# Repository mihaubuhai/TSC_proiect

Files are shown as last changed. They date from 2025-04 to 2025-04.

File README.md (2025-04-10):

# OpenBook e-book reader

## BOM - Bill of Materials

| Component | Datasheet | Vendor |
| --- | ---| ---|
| 112A-TAAR-R03_ATTEND | [datasheet](https://www.attend.com.tw/en/product.php?act=view&id=253) | [vendor](https://www.digikey.com/en/products/detail/attend-technology/112A-TAAR-R03/17633923) |
| BD5229G-TR | [datasheet](https://www.digikey.ph/en/products/detail/rohm-semiconductor/BD5229G-TR/658502) | [vendor](https://www.digikey.ph/en/products/detail/rohm-semiconductor/BD5229G-TR/658502) |
| BUTTON_COSYOMV1 | [datasheet](https://components101.com/switches/push-button) | [vendor](https://uk.farnell.com/wurth-elektronik/430182043816/switch-160gf-6x6mm-smd-4-3mm-act/dp/2065105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) |
| CPH3225A | [datasheet](https://www.digikey.com/en/products/detail/seiko-instruments/CPH3225A/8692444) | [vendor](https://www.digikey.com/en/products/detail/seiko-instruments/CPH3225A/8692444) |
| DS3231SN | [datasheet](https://www.digikey.com/en/products/detail/analog-devices-inc-maxim-integrated/DS3231SN/1197576) | [vendor](https://www.digikey.com/en/products/detail/analog-devices-inc-maxim-integrated/DS3231SN/1197576) |
| BME680 | [datasheet](https://www.sparkfun.com/sparkfun-environmental-sensor-breakout-bme680-qwiic.html) | [vendor](https://www.sparkfun.com/sparkfun-environmental-sensor-breakout-bme680-qwiic.html) |
| MCP73831 | [datasheet](https://www.microchip.com/en-us/product/mcp73831) | [vendor](https://www.microchipdirect.com/product/MCP73831T-2ADI/OT) |
| C6-WROOM-1-N8 | [datasheet](https://www.espressif.com/sites/default/files/documentation/esp32-c6-wroom-1_wroom-1u_datasheet_en.pdf) | [vendor](https://www.adafruit.com/product/5671) |
| FH34SRJ-24S-0.5SH_99_ | [datasheet](https://www.hirose.com/product/p/CL0580-1255-6-99) | [vendor](https://www.hirose.com/product/p/CL0580-1255-6-99) |
| MAX17048G+T10 | [datasheet](https://eu.mouser.com/ProductDetail/Analog-Devices-Maxim-Integrated/MAX17048G+T10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) | [vendor](https://eu.mouser.com/ProductDetail/Analog-Devices-Maxim-Integrated/MAX17048G+T10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) |
| MBR0530 | [datasheet](https://www.digikey.com/en/products/detail/onsemi/MBR0530/1048783) | [vendor](https://www.digikey.com/en/products/detail/onsemi/MBR0530/1048783) |
| PGB1010603MR | [datasheet](https://www.digikey.com/en/products/detail/littelfuse-inc/PGB1010603MR/715755) | [vendor](https://www.digikey.com/en/products/detail/littelfuse-inc/PGB1010603MR/715755) |
| SAMACSYS_PARTS_USB4110-GF-A | [datasheet](https://www.digikey.ro/en/products/detail/gct/USB4110-GF-A/10384547) | [vendor](https://www.digikey.ro/en/products/detail/gct/USB4110-GF-A/10384547) |
| SI1308EDL-T1-GE3 | [datasheet](https://www.digikey.com/en/products/detail/vishay-siliconix/SI1308EDL-T1-GE3/4876435) | [vendor](https://www.digikey.com/en/products/detail/vishay-siliconix/SI1308EDL-T1-GE3/4876435) |
| SJ | [datasheet](https://www.digikey.com/en/products/detail/cui-devices/SJ1-3514N/738685) | [vendor](https://www.digikey.com/en/products/detail/cui-devices/SJ1-3514N/738685) |
| USBLC6-2SC6Y | [datasheet](https://www.digikey.com/en/products/detail/stmicroelectronics/USBLC6-2SC6Y/2819177) | [vendor](https://www.digikey.com/en/products/detail/stmicroelectronics/USBLC6-2SC6Y/2819177) |
| W25Q512JVEIQ | [datasheet](https://www.digikey.com/en/products/detail/winbond-electronics/W25Q512JVEIQ/10244706) | [vendor](https://www.digikey.com/en/products/detail/winbond-electronics/W25Q512JVEIQ/10244706) |
| XC6220A331MR-G | [datasheet](https://www.digikey.com/en/products/detail/torex-semiconductor-ltd/XC6220B331MR-G/2138177) | [vendor](https://www.digikey.com/en/products/detail/torex-semiconductor-ltd/XC6220B331MR-G/2138177) |
| SD0805S020S1R0 | [datasheet](https://www.digikey.com/en/products/detail/kyocera-avx/SD0805S020S1R0/3749517) | [vendor](https://www.digikey.com/en/products/detail/kyocera-avx/SD0805S020S1R0/3749517) |
| LTSPICE_C 100nF | [datasheet](https://www.digikey.com/en/products/detail/nextgen-components/0402B104K500HI/22601924) | [vendor](https://www.digikey.com/en/products/detail/nextgen-components/0402B104K500HI/22601924) |
| LTSPICE_C 10nF | [datasheet](https://www.amazon.com/ALLECIN-Electrolytic-Capacitor-0-2x0-43in-Capacitors/dp/B0CMQC587X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) | [vendor](https://www.amazon.com/ALLECIN-Electrolytic-Capacitor-0-2x0-43in-Capacitors/dp/B0CMQC587X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) |
| LTSPICE_C 4.7uF | [datasheet](https://www.amazon.com/ALLECIN-Electrolytic-Capacitor-0-2x0-43in-Capacitors/dp/B0CMQC587X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) | [vendor](https://www.amazon.com/ALLECIN-Electrolytic-Capacitor-0-2x0-43in-Capacitors/dp/B0CMQC587X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) |
| LTSPICE_C 1uF | [datasheet](https://www.amazon.com/ALLECIN-Electrolytic-Capacitor-0-2x0-43in-Capacitors/dp/B0CMQC587X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) | [vendor](https://www.amazon.com/ALLECIN-Electrolytic-Capacitor-0-2x0-43in-Capacitors/dp/B0CMQC587X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) |
| LTSPICE_C 0.1uF | [datasheet](https://www.digikey.com/en/products/detail/samsung-electro-mechanics/CL10E104KC8VPNC/20498486) | [vendor](https://www.digikey.com/en/products/detail/samsung-electro-mechanics/CL10E104KC8VPNC/20498486) |
| ADAFRUIT_LED | [datasheet](https://www.adafruit.com/product/4684) | [vendor](https://www.adafruit.com/product/4684) |
| ESP32_VARISTOR | [datasheet](https://uk.rs-online.com/web/p/varistors/9012743) | [vendor](https://uk.rs-online.com/web/p/varistors/9012743) |
| CT3528 (RCL_CPOL-EU) 100uF | [datasheet](https://www.datasheetarchive.com/?q=ct3528) | [vendor](https://ro.mouser.com/ProductDetail/Panasonic/EEU-FS1K101L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) |
| DMG2305UX-7 20V/4.2A/52mO/1.4W | [datasheet](https://www.digikey.com/en/products/detail/diodes-incorporated/DMG2305UX-7/4340667) | [vendor](https://www.digikey.com/en/products/detail/diodes-incorporated/DMG2305UX-7/4340667) |
| IND-4828-WE-TPC-WRE | [datasheet](https://www.axel-gl.com/en/asone/d/64-0172-48/) | [vendor](https://www.axel-gl.com/en/asone/d/64-0172-48/) |
| JS-1MM(QWIIC_CONNECTOR) | [datasheet](https://www.sparkfun.com/qwiic-jst-connector-smd-4-pin-horizontal.html) | [vendor](https://www.sparkfun.com/qwiic-jst-connector-smd-4-pin-horizontal.html) |
| LTSPICE_R 5k1 | [datasheet](https://www.vishay.com/docs/53046/pfrr.pdf) | [vendor](https://www.amazon.com/BOJACK-Values-Resistor-Resistors-Assortment/dp/B08FD1XVL6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) |
| LTSPICE_R 100k | [datasheet](https://www.vishay.com/docs/53046/pfrr.pdf) | [vendor](https://www.amazon.com/BOJACK-Values-Resistor-Resistors-Assortment/dp/B08FD1XVL6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) |
| LTSPICE_R 2.2 | [datasheet](https://www.vishay.com/docs/53046/pfrr.pdf) | [vendor](https://www.amazon.com/BOJACK-Values-Resistor-Resistors-Assortment/dp/B08FD1XVL6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) |
| LTSPICE_R 10k | [datasheet](https://www.vishay.com/docs/53046/pfrr.pdf) | [vendor](https://www.amazon.com/BOJACK-Values-Resistor-Resistors-Assortment/dp/B08FD1XVL6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) |
| LTSPICE_R 0.47 | [datashet](https://www.vishay.com/docs/53046/pfrr.pdf) | [vendor](https://www.amazon.com/BOJACK-Values-Resistor-Resistors-Assortment/dp/B08FD1XVL6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) |
| LTSPICE_R 2k | [datasheet](https://www.vishay.com/docs/53046/pfrr.pdf) | [vendor](https://www.amazon.com/BOJACK-Values-Resistor-Resistors-Assortment/dp/B08FD1XVL6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) |
| LTSPICE_R 200 | [datasheet](https://www.vishay.com/docs/53046/pfrr.pdf) | [vendor](https://www.amazon.com/BOJACK-Values-Resistor-Resistors-Assortment/dp/B08FD1XVL6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) |
| LTSPICE_R 15 | [datasheet](https://www.vishay.com/docs/53046/pfrr.pdf) | [vendor](https://www.amazon.com/BOJACK-Values-Resistor-Resistors-Assortment/dp/B08FD1XVL6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) |
| Test Pad TP20R | [datasheet](https://us.misumi-ec.com/vona2/detail/221005496391/?HissuCode=TP20R-24) | [vendor](https://us.misumi-ec.com/vona2/detail/221005496391/?HissuCode=TP20R-24) |

#
```
        Microcontroler: ESP32-C6-WROOM-1-N1 (U2). Acesta este un microcontroler puternic cu conectivitate
    Wi-Fi, Bluetooth, care gestionează procesarea datelor, comunicațiile și controlul general
    al dispozitivului.

    Alimentare:
        Un conector USB-C furnizează intrarea principală de alimentare.
        Un regulator LDO de tensiune (IC4, XC6220A331MR-G) asigură o tensiune stabilă pentru componente.
        Un controler de încărcare pentru baterii Li-Po (MCP73831) gestionează încărcarea bateriei,
            permițând funcționarea autonomă.
        MAX17048G+T10 (U4) monitorizează nivelul de încărcare al bateriei.

        Stocare de date: O memorie Flash NOR externă (U1, W25Q512JVEIQ) oferă stocare non-volatilă
    pentru jurnalizarea datelor, firmware sau alte informații. Este prezent și un slot pentru card SD
    pentru stocare detașabilă.

        Ceas în timp real (RTC): Modulul RTC DS3231SN (U3) menține o măsurare precisă a timpului,
    esențială pentru marcarea temporală a datelor. Un supercondensator (C10) oferă alimentare de
    rezervă pentru RTC.

        Senzori de mediu: Un senzor BME688 măsoară parametrii de mediu (temperatură, umiditate).

        Afișaj: Un ecran E-Paper este utilizat pentru afișarea informațiilor. Interfața cu ecranul
    include un conector (FH34SR-24S-0.5SH_99) și circuitele de susținere.

    Interfață cu utilizatorul:
        Butoanele Boot și Reset permit controlul sistemului și actualizări de firmware.
        Un buton "Change" oferă o intrare din partea utilizatorului.

    Comunicație: ESP32-C6 oferă capabilități de comunicare wireless (Wi-Fi, Bluetooth).

    Alte componente:
        Dispozitive de protecție ESD (USBLC6-2SC6Y, PEMF050.1) protejează circuitul de descărcări
            electrostatice.
        Paduri de test sunt incluse pentru depanare și testare.
        Un conector Qwiic/Stemma QT permite conectarea ușoară a dispozitivelor externe I2C.
```

### Utilizarea pinilor ESP32-C6
```
    Pini de alimentare: Pinii conectați la 3V3 și GND furnizează alimentare și împământare pentru ESP32-C6.

        Comunicație USB: Pinii conectați la conectorul USB-C (prin protecție ESD) sunt utilizați pentru
    comunicația și alimentarea prin USB.

        Interfață card SD: Pinii conectați la slotul pentru card SD (DAT0, DAT1, DAT2, CMD, CLK) sunt
    utilizați pentru interfața cu cardul SD.

        Comunicație SPI: Pinii conectați la memoria Flash externă (W25Q512JVEIQ) (CS, SCK, DO, DI) sunt
    utilizați pentru comunicația SPI.

        Comunicație I2C: Pinii conectați la RTC (DS3231SN) și la conectorul Qwiic (SDA, SCL) sunt utilizați
    pentru comunicația I2C. Senzorul BME688 utilizează și el I2C, prin tag-ul I2C_PW.

    Pini GPIO:
        Pinii conectați la butoanele Boot, Reset și Change sunt utilizați ca pini de intrare/ieșire
            generală (GPIO) pentru a citi starea butoanelor.
        Pinii conectați la interfața ecranului E-Paper sunt GPIO-uri utilizate pentru a controla afișajul.
        Alți pini GPIO pot fi utilizați pentru semnale de control sau indicatori de stare.
```

# ERORI ACCEPTATE
```
        Am acceptat erorile cauzate de nerutarea pinilor GND deoarece am deja 2 planuri de masă puse pe pe placă,
    iar eu consider că nu este necesară rutarea acestor pini între ei, în final ei legându-se la masă.
```

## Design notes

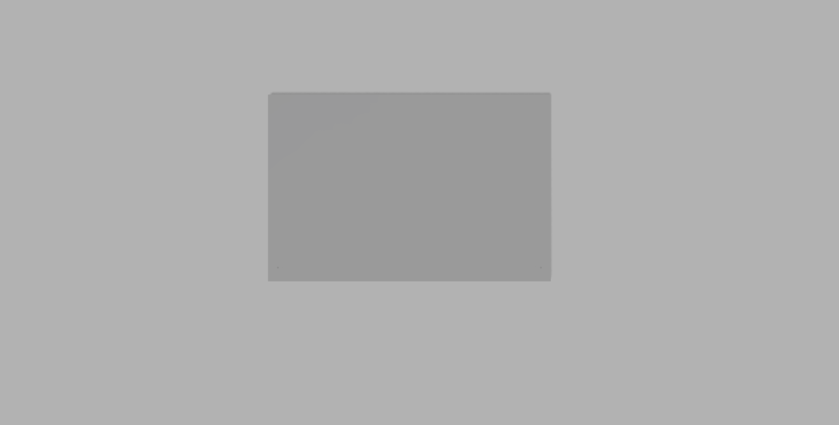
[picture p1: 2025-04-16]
Images/EpaperDisply v1 v1.png

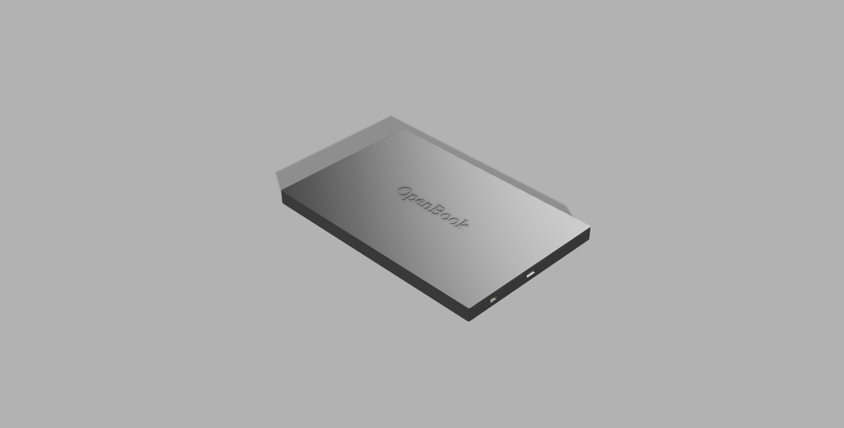
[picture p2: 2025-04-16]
Images/OpenBook Enclosure v4.png

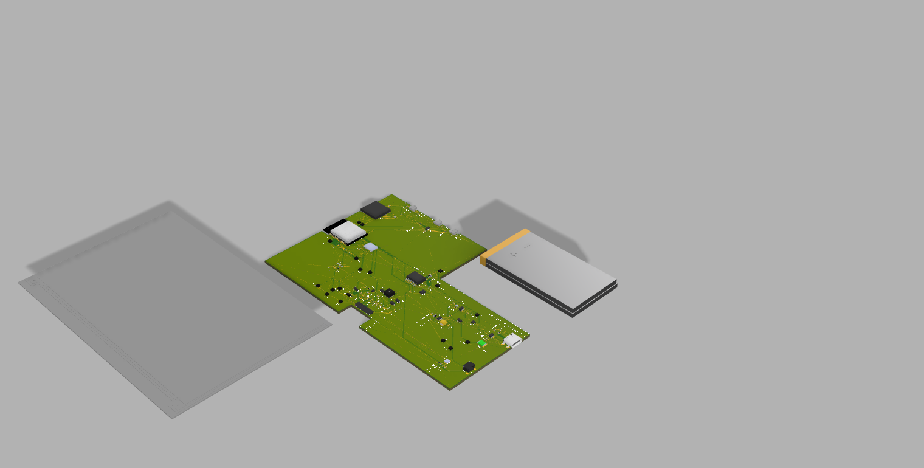
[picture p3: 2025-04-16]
Images/OpenBook Enclosure v5.png

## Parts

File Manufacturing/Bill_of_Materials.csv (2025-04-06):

Qty | Value | Device | Package | Parts | Description | ARROW_PART_NUMBER | ARROW_PRICE-STOCK | AVAILABILITY | CENTROID_NOT_SPECIFIED | CHECK_PRICES | COPYRIGHT | DATASHEET | DESCRIPTION | DIGIKEY_DESCRIPTION | DIGIKEY_PART_NUMBER | HEIGHT | LEAD_FREE | MANUFACTURER_NAME | MANUFACTURER_PART_NUMBER | MF | MFR_NAME | MOUSER_PART_NUMBER | MOUSER_PRICE-STOCK | MOUSER_TESTING_PART_NUMBER | MOUSER_TESTING_PRICE-STOCK | MP | MPN | PACKAGE | POPULARITY | PREFIX | PRICE | PROD_ID | PURCHASE-URL | ROHS | SNAPEDA_LINK | SPICEMODEL | SPICEPREFIX | TEMPERATURE_RANGE_HIGH | TEMPERATURE_RANGE_LOW | TP_SIGNAL_NAME | VALUE
1 |  | ADAFRUIT_LEDCHIP-LED0603 | ADAFRUIT_CHIP-LED0603 | CHG_LED | LED
1 |  | SJ | SJ | SJ1 | SMD solder JUMPER |  |  |  |  |  |  |  |  |  |  |  |  |  |  |  |  |  |  |  |  |  |  |  | 3
1 | 0.1uF/50V | ESP32_WROVER_EAGLE-LTSPICE_CC0402 | ESP32_WROVER_EAGLE-LTSPICE_C0402 | EPD_C5 | CAPACITOR, European symbol |  |  |  |  |  |  |  |  |  |  |  |  |  |  |  |  |  |  |  |  |  |  |  |  |  |  |  |  |  |  | NONE | C
1 | 0.47 | ESP32_WROVER_EAGLE-LTSPICE_RR0402 | ESP32_WROVER_EAGLE-LTSPICE_R0402 | R3 | RESISTOR, European symbol |  |  |  |  |  |  |  |  |  |  |  |  |  |  |  |  |  |  |  |  |  |  |  |  |  |  |  |  |  |  | NONE | R
1 | 100k | ESP32_WROVER_EAGLE-LTSPICE_RR0402 | ESP32_WROVER_EAGLE-LTSPICE_R0402 | R1_PWRUSB | RESISTOR, European symbol |  |  |  |  |  |  |  |  |  |  |  |  |  |  |  |  |  |  |  |  |  |  |  |  |  |  |  |  |  |  | NONE | R
8 | 100nF | ESP32_WROVER_EAGLE-LTSPICE_CC0402 | ESP32_WROVER_EAGLE-LTSPICE_C0402 | C1, C2, C4_USB, C6, C8, C9, C10, C_DELAY | CAPACITOR, European symbol |  |  |  |  |  |  |  |  |  |  |  |  |  |  |  |  |  |  |  |  |  |  |  |  |  |  |  |  |  |  | NONE | C
1 | 100uF TANT | RCL_CPOL-EUCT3528 | RCL_CT3528 | C3 | POLARIZED CAPACITOR, European symbol |  |  |  |  |  |  |  |  |  |  |  |  |  |  |  |  |  |  |  |  |  |  |  | 0 |  |  |  |  |  |  |  | C
16 | 10k | ESP32_WROVER_EAGLE-LTSPICE_RR0402 | ESP32_WROVER_EAGLE-LTSPICE_R0402 | R1, R1_PINH, R1_PINH1, R2_PINH, R2_PINH1, R4, R5, R6, R7, R8, R9, R10, R_BOOT, R_CHANGE, R_CL1, R_RESET | RESISTOR, European symbol |  |  |  |  |  |  |  |  |  |  |  |  |  |  |  |  |  |  |  |  |  |  |  |  |  |  |  |  |  |  | NONE | R
1 | 10uF | ESP32_WROVER_EAGLE-LTSPICE_CC0402 | ESP32_WROVER_EAGLE-LTSPICE_C0402 | C7 | CAPACITOR, European symbol |  |  |  |  |  |  |  |  |  |  |  |  |  |  |  |  |  |  |  |  |  |  |  |  |  |  |  |  |  |  | NONE | C
1 | 112A-TAAR-R03_ATTEND | 112A-TAAR-R03_ATTEND | 112ATAARR03ATTEND | J4 | Micro SD Card Socket, Push-Push Type, Top Mount, SMT, H=1.83mm, 10u |  |  |  |  |  |  |  | Micro SD Card Socket | Push-Push Type | Top Mount | SMT | H=1.83mm | 10u |  |  | 1.9mm |  | ATTEND | 112A-TAAR-R03 ATTEND
1 | 15 | ESP32_WROVER_EAGLE-LTSPICE_RR0402 | ESP32_WROVER_EAGLE-LTSPICE_R0402 | R_CAPACITOR | RESISTOR, European symbol |  |  |  |  |  |  |  |  |  |  |  |  |  |  |  |  |  |  |  |  |  |  |  |  |  |  |  |  |  |  | NONE | R
1 | 1uF | ESP32_WROVER_EAGLE-LTSPICE_CC0402 | ESP32_WROVER_EAGLE-LTSPICE_C0402 | C5 | CAPACITOR, European symbol |  |  |  |  |  |  |  |  |  |  |  |  |  |  |  |  |  |  |  |  |  |  |  |  |  |  |  |  |  |  | NONE | C
9 | 1uF/50V | ESP32_WROVER_EAGLE-LTSPICE_CC0402 | ESP32_WROVER_EAGLE-LTSPICE_C0402 | EPD_C1, EPD_C2, EPD_C6, EPD_C7, EPD_C8, EPD_C9, EPD_C10, EPD_C11, EPD_C12 | CAPACITOR, European symbol |  |  |  |  |  |  |  |  |  |  |  |  |  |  |  |  |  |  |  |  |  |  |  |  |  |  |  |  |  |  | NONE | C
1 | 2.2 | ESP32_WROVER_EAGLE-LTSPICE_RR0402 | ESP32_WROVER_EAGLE-LTSPICE_R0402 | R2 | RESISTOR, European symbol |  |  |  |  |  |  |  |  |  |  |  |  |  |  |  |  |  |  |  |  |  |  |  |  |  |  |  |  |  |  | NONE | R
1 | 200 | ESP32_WROVER_EAGLE-LTSPICE_RR0402 | ESP32_WROVER_EAGLE-LTSPICE_R0402 | R1_BAT | RESISTOR, European symbol |  |  |  |  |  |  |  |  |  |  |  |  |  |  |  |  |  |  |  |  |  |  |  |  |  |  |  |  |  |  | NONE | R
2 | 20V/4.2A/52mO/1.4W | ESP32_WROVER_SPARKFUN-DISCRETESEMI_MOSFET_PCH-DMG2305UX-7 | ESP32_WROVER_SPARKFUN-DISCRETESEMI_SOT23-3 | Q1, Q2 | P-channel MOSFETs |  |  |  |  |  |  |  |  |  |  |  |  |  |  |  |  |  |  |  |  |  |  |  |  |  |  | TRAN-14388 |  |  |  |  |  |  |  |  | 20V/4.2A/52mO/1.4W
1 | 2k | ESP32_WROVER_EAGLE-LTSPICE_RR0402 | ESP32_WROVER_EAGLE-LTSPICE_R0402 | R2_BAT | RESISTOR, European symbol |  |  |  |  |  |  |  |  |  |  |  |  |  |  |  |  |  |  |  |  |  |  |  |  |  |  |  |  |  |  | NONE | R
5 | 4.7uF | ESP32_WROVER_EAGLE-LTSPICE_CC0402 | ESP32_WROVER_EAGLE-LTSPICE_C0402 | C1_BAT, C1_BAT1, C1_BAT2, C2_BAT, C5_USB | CAPACITOR, European symbol |  |  |  |  |  |  |  |  |  |  |  |  |  |  |  |  |  |  |  |  |  |  |  |  |  |  |  |  |  |  | NONE | C
1 | 4.7uF/25V | ESP32_WROVER_EAGLE-LTSPICE_CC0402 | ESP32_WROVER_EAGLE-LTSPICE_C0402 | C4 | CAPACITOR, European symbol |  |  |  |  |  |  |  |  |  |  |  |  |  |  |  |  |  |  |  |  |  |  |  |  |  |  |  |  |  |  | NONE | C
2 | 5k1 | ESP32_WROVER_EAGLE-LTSPICE_RR0402 | ESP32_WROVER_EAGLE-LTSPICE_R0402 | R2-USB, R2-USB1 | RESISTOR, European symbol |  |  |  |  |  |  |  |  |  |  |  |  |  |  |  |  |  |  |  |  |  |  |  |  |  |  |  |  |  |  | NONE | R
1 | 68uH | 744043680IND_4828-WE-TPC_WRE | IND_4828-WE-TPC_WRE | L1 |  |  |  |  |  |  | Copyright (C) 2024 Ultra Librarian. All rights reserved. |  |  |  |  |  |  |  | 744043680 |  | Wurth Electronics
1 | BD5229G-TR | BD5229G-TR | SOT95P280X125-5N | IC1 | Voltage Detector with Adjustable Delay Time: CMOS processes are utilized to develop high precision, low current consumption CMOS reset ICs that allow arbitrary setting of the delay time. The extensive lineup includes both Nch Open Drain and CMOS output types in a wide range of detection voltages (from 2.3V to 6.0V, in 0.1V steps), enabling selection of the ideal solution based on customer requirements. In addition, the entire series is of course both lead-free and RoHS-compliant. |  |  |  |  |  |  |  | Voltage Detector with Adjustable Delay Time: CMOS processes are utilized to develop high precision | low current consumption CMOS reset ICs that allow arbitrary setting of the delay time. The extensive lineup includes both Nch Open Drain and CMOS output types in a wide range of detection voltages (from 2.3V to 6.0V | in 0.1V steps) | enabling selection of the ideal solution based on customer requirements. In addition | the entire series is of course both lead-free and RoHS-compliant. |  |  | 1.25mm |  | ROHM Semiconductor | BD5229G-TR |  |  | 755-BD5229G-TR | https://www.mouser.co.uk/ProductDetail/ROHM-Semiconductor/BD5229G-TR?qs=4kLU8WoGk0vvnhrrYwdszw%3D%3D
1 | BME688 | ESP32_WROVER_BME680_BME680 | ESP32_WROVER_BME680_PSON80P300X300X100-8N | SENSOR2 | Integrated Environmental Unit |  |  | Unavailable |  |  |  |  | Integrated Environmental Unit |  |  |  |  |  |  | Bosch Sensortec |  |  |  |  |  | BME680 |  | LGA-8 Bosch Tools |  |  | None
3 | BUTTON_CUSYOMV1 | BUTTON_CUSYOMV1 | MYBUTTON | BOOT_BUTTON, CHANGE_BUTTON, RESET_BUTTON
1 | CPH3225A | CPH3225A | CAPCP3225X100N | C10_SUPERCAP | Cap 0.011F 3.3V 1210 Flat Check availability |  |  | Not in stock |  | https://www.snapeda.com/parts/CPH3225A/Seiko+Instruments/view-part/?ref=eda |  |  | 11 mF (EDLC) Supercapacitor 3.3 V 1210 (3225 Metric) - - |  |  |  |  |  |  | Seiko Instruments |  |  |  |  |  | CPH3225A |  | 1210 Seiko |  |  | None |  | https://www.snapeda.com/api/url_track_click_mouser/?unipart_id=562593&manufacturer=Seiko Instruments&part_name=CPH3225A&search_term=None |  | https://www.snapeda.com/parts/CPH3225A/Seiko+Instruments/view-part/?ref=snap
1 | DS3231SN# | DS3231SN# | SOIC127P1032X265-16N | U1 | Real Time Clock Serial 16-Pin SOIC W T/R Check availability |  |  | In Stock |  | https://www.snapeda.com/parts/DS3231SN%23/Analog+Devices/view-part/?ref=eda |  |  | Extremely Accurate I²C-Integrated RTC/TCXO/Crystal |  |  |  |  |  |  | Analog Devices |  |  |  |  |  | DS3231SN# |  | SOIC-16 Maxim |  |  | None |  | https://www.snapeda.com/api/url_track_click_mouser/?unipart_id=99048&manufacturer=Analog Devices&part_name=DS3231SN#&search_term=None |  | https://www.snapeda.com/parts/DS3231SN%23/Analog+Devices/view-part/?ref=snap
1 | ESP32-C6-WROOM-1-N8 | ESP32-C6-WROOM-1-N8 | XCVR_ESP32-C6-WROOM-1-N8 | U2 | Check availability |  |  | In Stock |  | https://www.snapeda.com/parts/ESP32-C6-WROOM-1-N8/Espressif+Systems/view-part/?ref=eda |  |  | Multiprotocol Modules ESP32-C6 module | Wi-Fi 6 in 2.4 GHz band | Bluetooth 5 | Zigbee 3.0 and Thread. ESP34-WROOM Compatible - ENGINEERING SAMPLE |  |  |  |  |  |  | Espressif Systems |  |  |  |  |  | ESP32-C6-WROOM-1-N8 |  | None |  |  | None |  |  |  | https://www.snapeda.com/parts/ESP32-C6-WROOM-1-N8/Espressif+Systems/view-part/?ref=snap
1 | ESP32C6_VARISTORCN1812 | ESP32C6_VARISTORCN1812 | ESP32C6_VARISTOR_CT/CN1812 | PFMF.050.1 | VARISTOR |  |  |  |  |  |  |  |  |  |  |  |  |  |  |  |  |  |  |  |  |  |  |  | 0
2 | ESP32_WROVER_AVX---SD0805S020S1R0_AVX_SD0805S020S1R0_0_0AVX_SD0805S020S1R0_0_0 | ESP32_WROVER_AVX---SD0805S020S1R0_AVX_SD0805S020S1R0_0_0AVX_SD0805S020S1R0_0_0 | ESP32_WROVER_AVX---SD0805S020S1R0_AVX_SD0805S020S1R0_0 | D2, D7 | Schottky Barrier Rectifier Diode |  |  |  | No |  |  | http://datasheets.avx.com/schottky.pdf |  | DIODE SCHOTTKY 20V 1A 0805 | 478-7800-1-ND |  | yes |  |  | AVX |  | 581-SD0805S020S1R0 |  |  |  |  |  | 0805 (2012 metric) |  | D |  |  |  | yes |  |  |  | +125°C | -55°C
1 | ESP32_WROVER_SPARKFUN-IC-POWER_MCP73831 | ESP32_WROVER_SPARKFUN-IC-POWER_MCP73831 | ESP32_WROVER_SPARKFUN-IC-POWER_SOT23-5 | MCP73831 | MCP73831T Li-Ion, Li-Pol Controller |  |  |  |  |  |  |  |  |  |  |  |  |  |  |  |  |  |  |  |  |  |  |  |  |  |  | IC-09995
1 | FH34SRJ-24S-0.5SH_99_ | FH34SRJ-24S-0.5SH_99_ | FH34SRJ24S05SH99 | J1 | (0.50mm) Surface Mount, Right Angle |  |  |  |  |  |  |  | 24 Position FFC | FPC Connector Contacts | (0.50mm) Surface Mount | Right Angle |  |  | 1.1mm |  | Hirose | FH34SRJ-24S-0.5SH(99) |  |  | 798-FH34SRJ24S05SH99 | https://www.mouser.co.uk/ProductDetail/Hirose-Connector/FH34SRJ-24S-0.5SH99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
1 | MAX17048G+T10 | MAX17048G+T10 | SON50P200X200X80-9N | U4 | Check availability |  |  | In Stock |  | https://www.snapeda.com/parts/MAX17048G+T10/Analog+Devices/view-part/?ref=eda |  |  | 3µA 1-Cell/2-Cell Fuel Gauge with ModelGauge |  |  |  |  |  |  | Analog Devices |  |  |  |  |  | MAX17048G+T10 |  | TDFN-8 Maxim |  |  | None |  | https://www.snapeda.com/api/url_track_click_mouser/?unipart_id=329239&manufacturer=Analog Devices&part_name=MAX17048G+T10&search_term=None |  | https://www.snapeda.com/parts/MAX17048G+T10/Analog+Devices/view-part/?ref=snap
3 | MBR0530 | MBR0530 | SOD3716X135N | D3, D4, D5 | ON SEMICONDUCTOR - MBR0530 - DIODE, SCHOTTKY, 0.5A, 30V, SOD-123 |  |  | In Stock |  | https://www.snapeda.com/parts/MBR0530/Onsemi/view-part/?ref=eda |  |  | Diode Schottky 30 V 500mA Surface Mount SOD-123 |  |  |  |  |  |  | ON Semiconductor |  |  |  |  |  | MBR0530 |  | SOD-123-2 ON Semiconductor |  |  | None |  | https://www.snapeda.com/api/url_track_click_mouser/?unipart_id=179458&manufacturer=ON Semiconductor&part_name=MBR0530&search_term=None |  | https://www.snapeda.com/parts/MBR0530/Onsemi/view-part/?ref=snap
6 | PGB1010603MR | PGB1010603MR | DIOC1608X36N | D6, D8, D9, D10, D11, D12 | Check availability |  |  | In Stock |  | https://www.snapeda.com/parts/PGB1010603MR/Littelfuse/view-part/?ref=eda |  |  | 150V (Typ) Clamp - Ipp Tvs Diode Surface Mount 0603 (1608 Metric) |  |  |  |  |  |  | Littelfuse Inc. |  |  |  |  |  | PGB1010603MR |  | 0603 Littelfuse Inc. |  |  | None |  | https://www.snapeda.com/api/url_track_click_mouser/?unipart_id=5659453&manufacturer=Littelfuse Inc.&part_name=PGB1010603MR&search_term=None |  | https://www.snapeda.com/parts/PGB1010603MR/Littelfuse/view-part/?ref=snap
1 | QWIIC_RIGHT_ANGLE | QWIIC_CONNECTORJS-1MM | JST04_1MM_RA | J3 | SparkFun I2C Standard Qwiic Connector |  |  |  |  |  |  |  |  |  |  |  |  |  |  |  |  |  |  |  |  |  |  |  |  |  |  | CONN-13694 |  |  |  |  |  |  |  |  | QWIIC_RIGHT_ANGLE
1 | SAMACSYS_PARTS_USB4110-GF-A | SAMACSYS_PARTS_USB4110-GF-A | SAMACSYS_PARTS_USB4110GFA | J2 | CONN USB 2.0 TYPE-C R/A SMT |  |  |  |  |  |  |  | CONN USB 2.0 TYPE-C R/A SMT |  |  | 3.26mm |  | GCT (GLOBAL CONNECTOR TECHNOLOGY) | USB4110-GF-A |  |  | 640-USB4110-GF-A | https://www.mouser.co.uk/ProductDetail/GCT/USB4110-GF-A?qs=KUoIvG%2F9IlYiZvIXQjyJeA%3D%3D
1 | SI1308EDL-T1-GE3 | SI1308EDL-T1-GE3 | SOT65P210X110-3N | Q3 | MOSFET N-Ch 30V 1.5A TrenchFET SC70 Vishay Si1308EDL-T1-GE3 N-channel MOSFET Transistor, 1.5 A, 30 V, 3-Pin SC-70 |  |  | In Stock |  | https://www.snapeda.com/parts/SI1308EDL-T1-GE3/Vishay+Siliconix/view-part/?ref=eda |  |  | Si1308EDL-T1-GE3 N-channel MOSFET Transistor | 1.5 A | 30 V | 3-Pin SC-70 | Siliconix / Vishay SI1308EDL-T1-GE3 |  |  |  |  |  |  | Vishay Siliconix |  |  |  |  |  | SI1308EDL-T1-GE3 |  | SOT-323 Vishay Semiconductor |  |  | None |  | https://www.snapeda.com/api/url_track_click_mouser/?unipart_id=274603&manufacturer=Vishay Siliconix&part_name=SI1308EDL-T1-GE3&search_term=None |  | https://www.snapeda.com/parts/SI1308EDL-T1-GE3/Vishay+Siliconix/view-part/?ref=snap
17 | TPTP20R | TPTP20R | TP20R | TP1, TP2, TP3, TP4, TP5, TP6, TP7, TP8, TP9, TP10, TP11, TP12, TP13, TP14, TP15, TP16, TP17 | Test pad |  |  |  |  |  |  |  |  |  |  |  |  |  |  |  |  |  |  |  |  |  |  |  | 2
1 | USBLC6-2SC6Y | USBLC6-2SC6Y | SOT95P280X145-6N | D1 | Low Cap. ESD Protection Auto SOT-23-6 STMicroelectronics USBLC6-2SC6Y, Dual Uni-Directional TVS Diode Array, 6-Pin SOT-23 |  |  | In Stock |  | https://www.snapeda.com/parts/USBLC6-2SC6Y/STMicroelectronics/view-part/?ref=eda |  |  | 17V Clamp 5A (8/20µs) Ipp Tvs Diode Surface Mount SOT-23-6 |  |  |  |  |  |  | STMicroelectronics |  |  |  |  |  | USBLC6-2SC6Y |  | SOT-23-6 STMicroelectronics |  |  | None |  |  |  | https://www.snapeda.com/parts/USBLC6-2SC6Y/STMicroelectronics/view-part/?ref=snap
1 | W25Q512JVEIQ | W25Q512JVEIQ | SON127P600X800X80-9N | U3 | Check availability |  |  | In Stock |  | https://www.snapeda.com/parts/W25Q512JVEIQ/Winbond+Electronics/view-part/?ref=eda |  |  | FLASH - NOR Memory IC 512Mb (64M x 8) SPI - Quad I/O 133 MHz 8-WSON (8x6) |  |  |  |  |  |  | Winbond Electronics |  |  |  |  |  | W25Q512JVEIQ |  | Package |  |  | None |  |  |  | https://www.snapeda.com/parts/W25Q512JVEIQ/Winbond+Electronics/view-part/?ref=snap
1 | XC6220A331MR-G | XC6220A331MR-G | SOT95P280X120-5N | IC4 | LDO Voltage Regulators |  |  |  |  |  |  |  | LDO Voltage Regulators |  |  | 1.2mm |  | Torex | XC6220A331MR-G |  |  | 865-XC6220A331MR-G | https://www.mouser.co.uk/ProductDetail/Torex-Semiconductor/XC6220A331MR-G?qs=AsjdqWjXhJ8ZSWznL1J0gg%3D%3D

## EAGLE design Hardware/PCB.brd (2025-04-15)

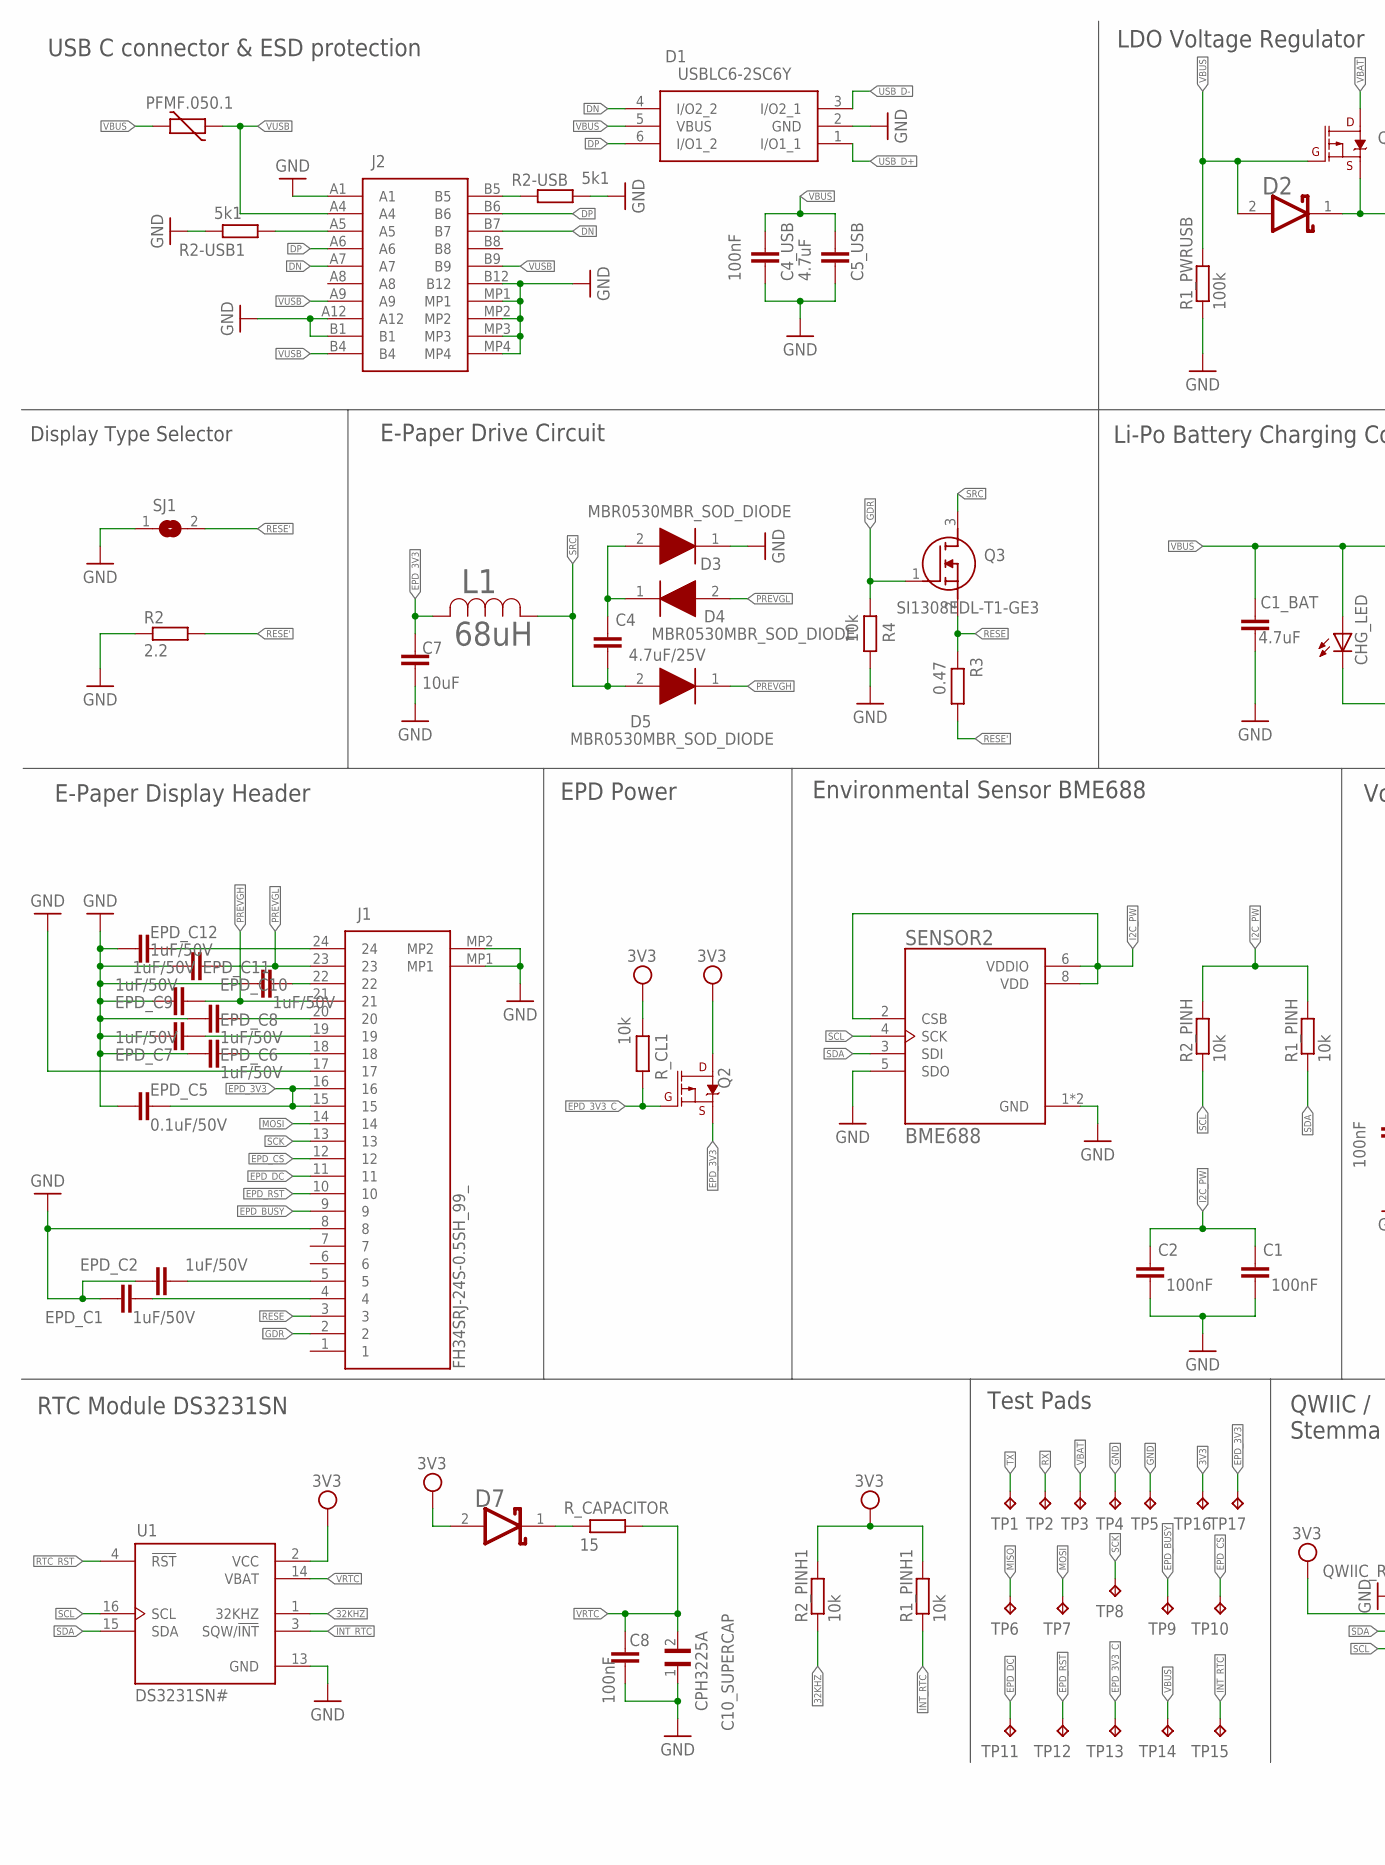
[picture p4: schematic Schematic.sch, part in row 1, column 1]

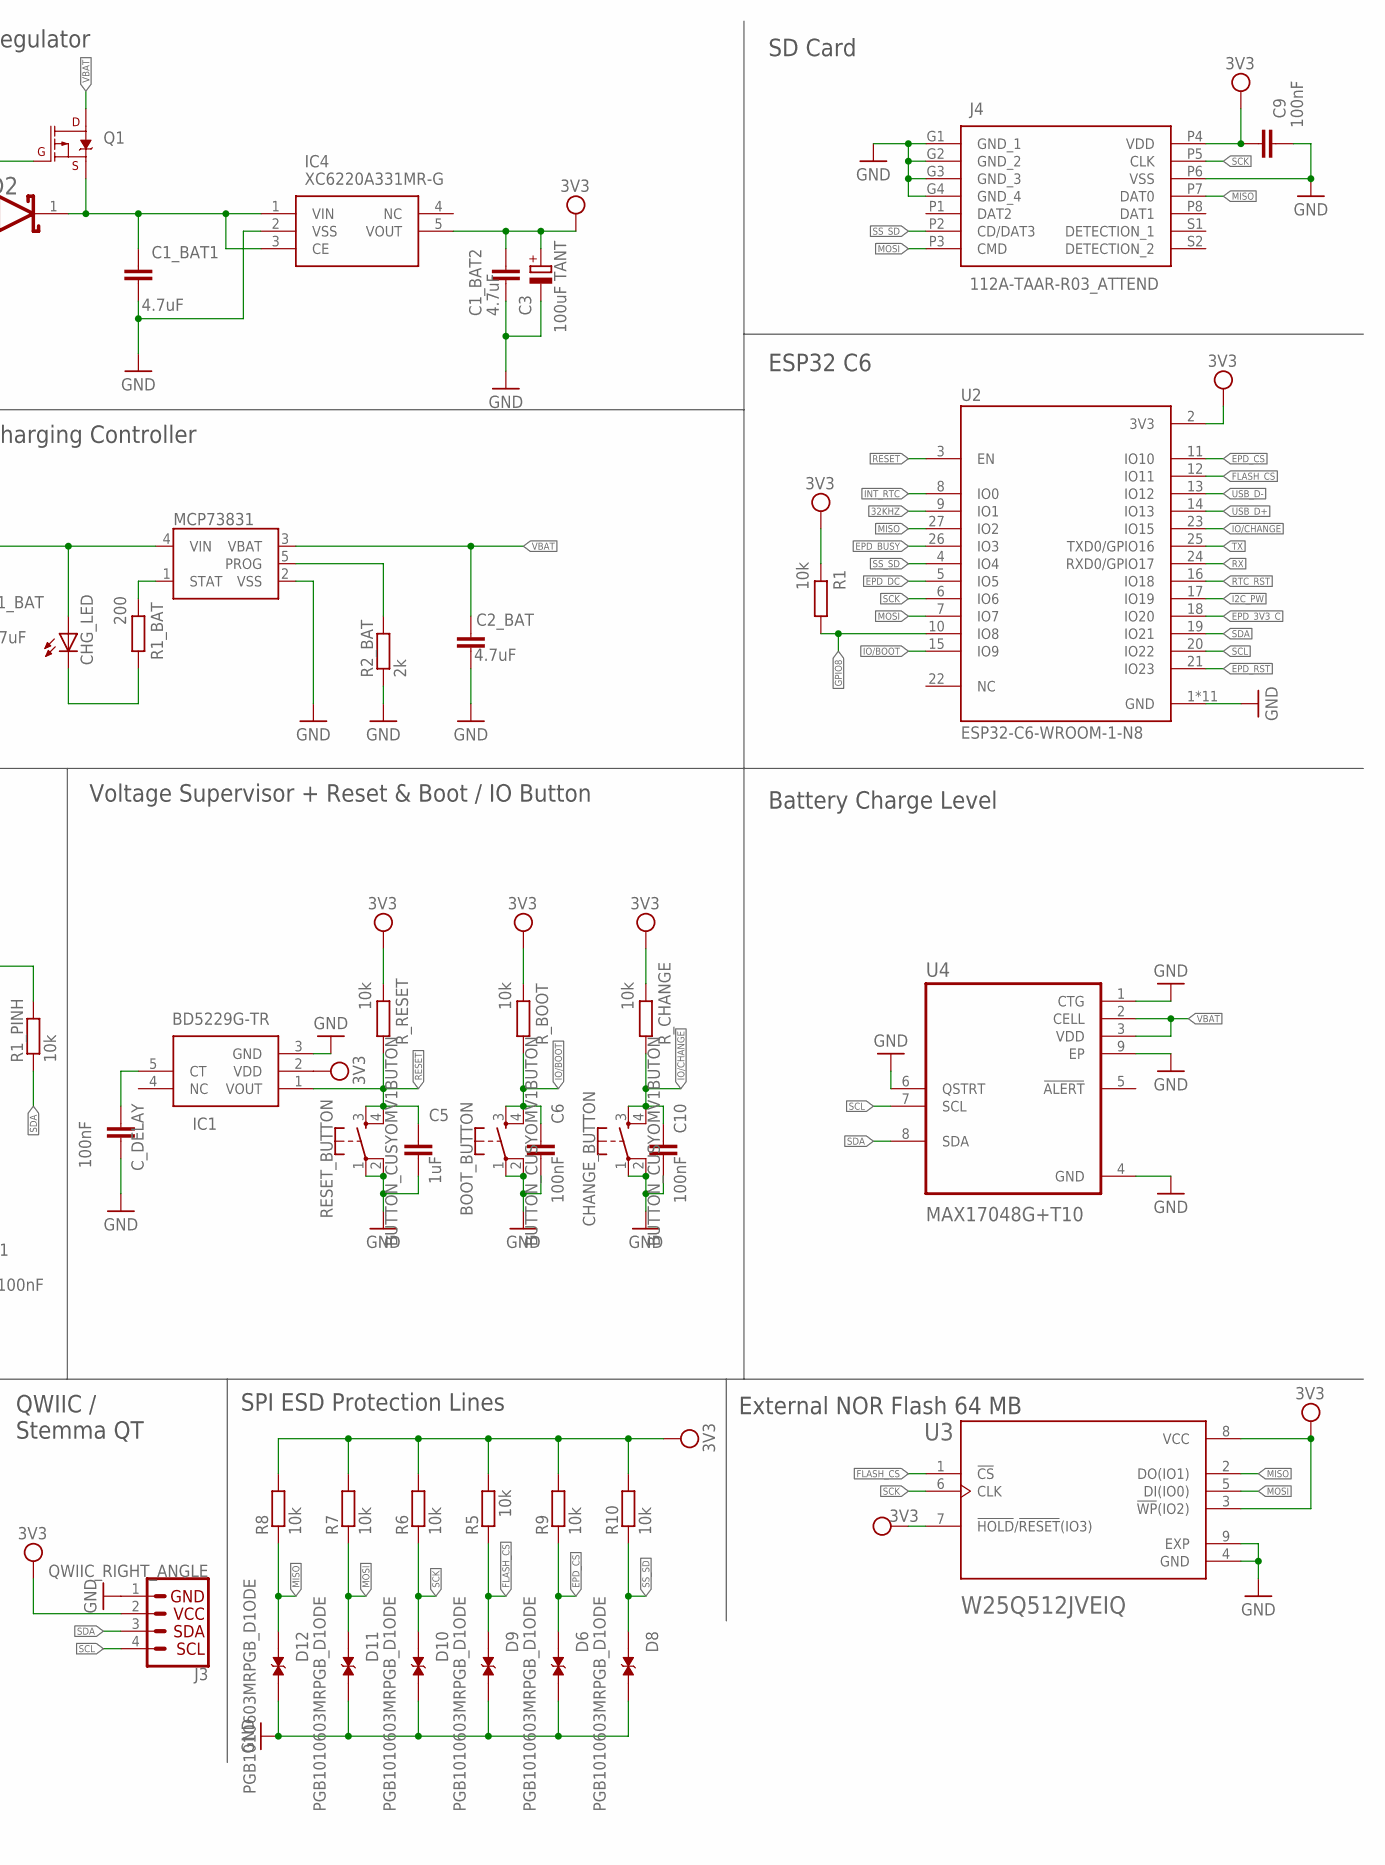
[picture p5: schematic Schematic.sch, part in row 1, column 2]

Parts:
BOOT_BUTTON: BUTTON_CUSYOMV1BUTON; MYBUTTON
C1, C2, C4_USB, C6, C8, C9, C10: 100nF; ESP32_WROVER_EAGLE-LTSPICE_C0402
C1_BAT, C1_BAT1, C1_BAT2, C2_BAT, C5_USB: 4.7uF; ESP32_WROVER_EAGLE-LTSPICE_C0402
C3: 100uF TANT; RCL_CT3528
C4: 4.7uF/25V; ESP32_WROVER_EAGLE-LTSPICE_C0402
C5: 1uF; ESP32_WROVER_EAGLE-LTSPICE_C0402
C7: 10uF; ESP32_WROVER_EAGLE-LTSPICE_C0402
C10_SUPERCAP: CPH3225A; CAPCP3225X100N
CHANGE_BUTTON: BUTTON_CUSYOMV1BUTON; MYBUTTON
CHG_LED: ADAFRUIT_LEDCHIP-LED0603; ADAFRUIT_CHIP-LED0603
C_DELAY: 100nF; ESP32_WROVER_EAGLE-LTSPICE_C0402
D1: USBLC6-2SC6Y; SOT95P280X145-6N
D2, D7: ESP32_WROVER_AVX---SD0805S020S1R0_AVX_SD0805S020S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; ESP32_WROVER_AVX---SD0805S020S1R0_AVX_SD0805S020S1R0_0
D3, D4, D5: MBR0530MBR_SOD_DIODE; SOD3716X135N
D6, D8, D9, D10, D11, D12: PGB1010603MRPGB_D1ODE; DIOC1608X36N
EPD_C1, EPD_C2, EPD_C6, EPD_C7, EPD_C8, EPD_C9, EPD_C10, EPD_C11, EPD_C12: 1uF/50V; ESP32_WROVER_EAGLE-LTSPICE_C0402
EPD_C5: 0.1uF/50V; ESP32_WROVER_EAGLE-LTSPICE_C0402
IC1: BD5229G-TR; SOT95P280X125-5N
IC4: XC6220A331MR-G; SOT95P280X120-5N
J1: FH34SRJ-24S-0.5SH_99_; FH34SRJ24S05SH99
J2: SAMACSYS_PARTS_USB4110-GF-A; SAMACSYS_PARTS_USB4110GFA
J3: QWIIC_RIGHT_ANGLE; JST04_1MM_RA
J4: 112A-TAAR-R03_ATTEND; 112ATAARR03ATTEND
L1: 68uH; IND_4828-WE-TPC_WRE
MCP73831: ESP32_WROVER_SPARKFUN-IC-POWER_MCP73831; ESP32_WROVER_SPARKFUN-IC-POWER_SOT23-5
PFMF.050.1: ESP32C6_VARISTORPFMF_ESP32C6_VARISTORS; ESP32C6_VARISTOR_CT/CN1812
Q1, Q2: 20V/4.2A/52mΩ/1.4W; ESP32_WROVER_SPARKFUN-DISCRETESEMI_SOT23-3
Q3: SI1308EDL-T1-GE3; SOT65P210X110-3N
R1, R1_PINH, R1_PINH1, R2_PINH, R2_PINH1, R4, R5, R6, R7, R8, R9, R10: 10k; ESP32_WROVER_EAGLE-LTSPICE_R0402
R1_BAT: 200; ESP32_WROVER_EAGLE-LTSPICE_R0402
R1_PWRUSB: 100k; ESP32_WROVER_EAGLE-LTSPICE_R0402
R2: 2.2; ESP32_WROVER_EAGLE-LTSPICE_R0402
R2-USB, R2-USB1: 5k1; ESP32_WROVER_EAGLE-LTSPICE_R0402
R2_BAT: 2k; ESP32_WROVER_EAGLE-LTSPICE_R0402
R3: 0.47; ESP32_WROVER_EAGLE-LTSPICE_R0402
RESET_BUTTON: BUTTON_CUSYOMV1BUTON; MYBUTTON
R_BOOT: 10k; ESP32_WROVER_EAGLE-LTSPICE_R0402
R_CAPACITOR: 15; ESP32_WROVER_EAGLE-LTSPICE_R0402
R_CHANGE: 10k; ESP32_WROVER_EAGLE-LTSPICE_R0402
R_CL1: 10k; ESP32_WROVER_EAGLE-LTSPICE_R0402
R_RESET: 10k; ESP32_WROVER_EAGLE-LTSPICE_R0402
SENSOR2: BME688; ESP32_WROVER_BME680_PSON80P300X300X100-8N
SJ1: SJ
TP1, TP2, TP3, TP4, TP5, TP6, TP7, TP8, TP9, TP10, TP11, TP12, TP13, TP14, TP15, TP16, TP17: TPTP20R; TP20R
U1: DS3231SN#; SOIC127P1032X265-16N
U2: ESP32-C6-WROOM-1-N8; XCVR_ESP32-C6-WROOM-1-N8
U3: W25Q512JVEIQ; SON127P600X800X80-9N
U4: MAX17048G+T10; SON50P200X200X80-9N

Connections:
3V3: C1_BAT2.1, C3.+, C9.1, D7.2 (ANODE), IC1.2 (VDD), IC4.5 (VOUT), J3.2, J4.P4 (VDD), Q2.3 (D), R1.2, R1_PINH1.2, R2_PINH1.2, R5.2, R6.2, R7.2, R8.2, R9.2, R10.2, R_BOOT.2, R_CHANGE.2, R_CL1.2, R_RESET.2, TP16.TP, U1.2 (VCC), U2.2 (3V3), U3.3 (!WP!(IO2)), U3.7 (!HOLD!/!RESET!(IO3)), U3.8 (VCC)
32KHZ: R2_PINH1.1, U1.1 (32KHZ), U2.9 (IO1)
DN: D1.4 (I/O2_2), J2.A7, J2.B7
DP: D1.6 (I/O1_2), J2.A6, J2.B6
EPD_3V3: C7.2, EPD_C5.2, J1.15, J1.16, L1.2, Q2.2 (S), TP17.TP
EPD_3V3_C: Q2.1 (G), R_CL1.1, TP13.TP, U2.18 (IO20)
EPD_BUSY: J1.9, TP9.TP, U2.26 (IO3)
EPD_CS: D6.1, J1.12, R9.1, TP10.TP, U2.11 (IO10)
EPD_DC: J1.11, TP11.TP, U2.5 (IO5)
EPD_RST: J1.10, TP12.TP, U2.21 (IO23)
FLASH_CS: D9.1, R5.1, U2.12 (IO11), U3.1 (!CS)
GDR: J1.2, Q3.1 (G), R4.2
GND: BOOT_BUTTON.1, BOOT_BUTTON.2, C1.2, C1_BAT.2, C1_BAT1.2, C1_BAT2.2, C2.2, C2_BAT.2, C3.-, C4_USB.2, C5.2, C5_USB.2, C6.2, C7.1, C8.1, C9.2, C10.2, C10_SUPERCAP.1, CHANGE_BUTTON.1, CHANGE_BUTTON.2, C_DELAY.2, D1.2 (GND), D3.1 (K), D6.2, D8.2, D9.2, D10.2, D11.2, D12.2, EPD_C1.1, EPD_C2.1, EPD_C5.1, EPD_C6.1, EPD_C7.1, EPD_C8.1, EPD_C9.1, EPD_C10.1, EPD_C11.1, EPD_C12.1, IC1.3 (GND), IC4.2 (VSS), J1.8, J1.17, J1.MP1, J1.MP2, J2.A1, J2.A12, J2.B1, J2.B12, J2.MP1, J2.MP2, J2.MP3, J2.MP4, J3.1, J4.G1 (GND_1), J4.G2 (GND_2), J4.G3 (GND_3), J4.G4 (GND_4), J4.P6 (VSS), MCP73831.2 (VSS), R1_PWRUSB.1, R2.1, R2-USB.2, R2-USB1.1, R2_BAT.1, R4.1, RESET_BUTTON.1, RESET_BUTTON.2, SENSOR2.1 (GND), SENSOR2.5 (SDO), SENSOR2.7 (GND), SJ1.1, TP4.TP, TP5.TP, U1.13 (GND), U2.1 (GND), U2.28 (GND), U2.29_1 (GND), U2.29_2 (GND), U2.29_3 (GND), U2.29_4 (GND), U2.29_5 (GND), U2.29_6 (GND), U2.29_7 (GND), U2.29_8 (GND), U2.29_9 (GND), U3.4 (GND), U3.9 (EXP), U4.1 (CTG), U4.4 (GND), U4.6 (QSTRT), U4.9 (EP)
GPIO8: R1.1, U2.10 (IO8)
I2C_PW: C1.1, C2.1, R1_PINH.2, R2_PINH.2, SENSOR2.2 (CSB), SENSOR2.6 (VDDIO), SENSOR2.8 (VDD), U2.17 (IO19)
INT_RTC: R1_PINH1.1, TP15.TP, U1.3 (SQW/!INT), U2.8 (IO0)
IO/BOOT: BOOT_BUTTON.3, BOOT_BUTTON.4, C6.1, R_BOOT.1, U2.15 (IO9)
IO/CHANGE: C10.1, CHANGE_BUTTON.3, CHANGE_BUTTON.4, R_CHANGE.1, U2.23 (IO15)
MISO: D12.1, J4.P7 (DAT0), R8.1, TP6.TP, U2.27 (IO2), U3.2 (DO(IO1))
MOSI: D11.1, J1.14, J4.P3 (CMD), R7.1, TP7.TP, U2.7 (IO7), U3.5 (DI(IO0))
unnamed: J2.B5, R2-USB.1
unnamed: J2.A5, R2-USB1.2
unnamed: C1_BAT1.1, D2.1 (CATHODE), IC4.1 (VIN), IC4.3 (CE), Q1.2 (S)
unnamed: MCP73831.1 (STAT), R1_BAT.2
unnamed: MCP73831.5 (PROG), R2_BAT.2
unnamed: CHG_LED.C, R1_BAT.1
unnamed: C4.1, D3.2 (A), D4.1 (K)
unnamed: EPD_C6.2, J1.18
unnamed: EPD_C7.2, J1.19
unnamed: EPD_C8.2, J1.20
unnamed: C_DELAY.1, IC1.5 (CT)
unnamed: EPD_C10.2, J1.22
unnamed: D7.1 (CATHODE), R_CAPACITOR.2
unnamed: EPD_C12.2, J1.24
unnamed: EPD_C1.2, J1.4
unnamed: EPD_C2.2, J1.5
PREVGH: D5.1 (K), EPD_C9.2, J1.21
PREVGL: D4.2 (A), EPD_C11.2, J1.23
RESE: J1.3, Q3.2 (S), R3.2
RESE': R2.2, R3.1, SJ1.2
RESET: C5.1, IC1.1 (VOUT), RESET_BUTTON.3, RESET_BUTTON.4, R_RESET.1, U2.3 (EN)
RTC_RST: U1.4 (!RST), U2.16 (IO18)
RX: TP2.TP, U2.24 (RXD0/GPIO17)
SCK: D10.1, J1.13, J4.P5 (CLK), R6.1, TP8.TP, U2.6 (IO6), U3.6 (CLK)
SCL: J3.4, R2_PINH.1, SENSOR2.4 (SCK), U1.16 (SCL), U2.20 (IO22), U4.7 (SCL)
SDA: J3.3, R1_PINH.1, SENSOR2.3 (SDI), U1.15 (SDA), U2.19 (IO21), U4.8 (SDA)
SRC: C4.2, D5.2 (A), L1.1, Q3.3 (D)
SS_SD: D8.1, J4.P2 (CD/DAT3), R10.1, U2.4 (IO4)
TX: TP1.TP, U2.25 (TXD0/GPIO16)
USB_D+: D1.1 (I/O1_1), U2.14 (IO13)
USB_D-: D1.3 (I/O2_1), U2.13 (IO12)
VBAT: C2_BAT.1, MCP73831.3 (VBAT), Q1.3 (D), TP3.TP, U4.2 (CELL), U4.3 (VDD)
VBUS: C1_BAT.1, C4_USB.1, C5_USB.1, CHG_LED.A, D1.5 (VBUS), D2.2 (ANODE), MCP73831.4 (VIN), PFMF.050.1.2, Q1.1 (G), R1_PWRUSB.2, TP14.TP
VRTC: C8.2, C10_SUPERCAP.2, R_CAPACITOR.1, U1.14 (VBAT)
VUSB: J2.A4, J2.A9, J2.B4, J2.B9, PFMF.050.1.1

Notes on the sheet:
USB C connector & ESD protection
LDO Voltage Regulator
SD Card
ESP32 C6
Li-Po Battery Charging Controller
E-Paper Drive Circuit
Display Type Selector
E-Paper Display Header
EPD Power
Environmental Sensor BME688
Voltage Supervisor + Reset & Boot / IO Button
Battery Charge Level
RTC Module DS3231SN
Test Pads
QWIIC / Stemma QT
SPI ESD Protection Lines
External NOR Flash 64 MB

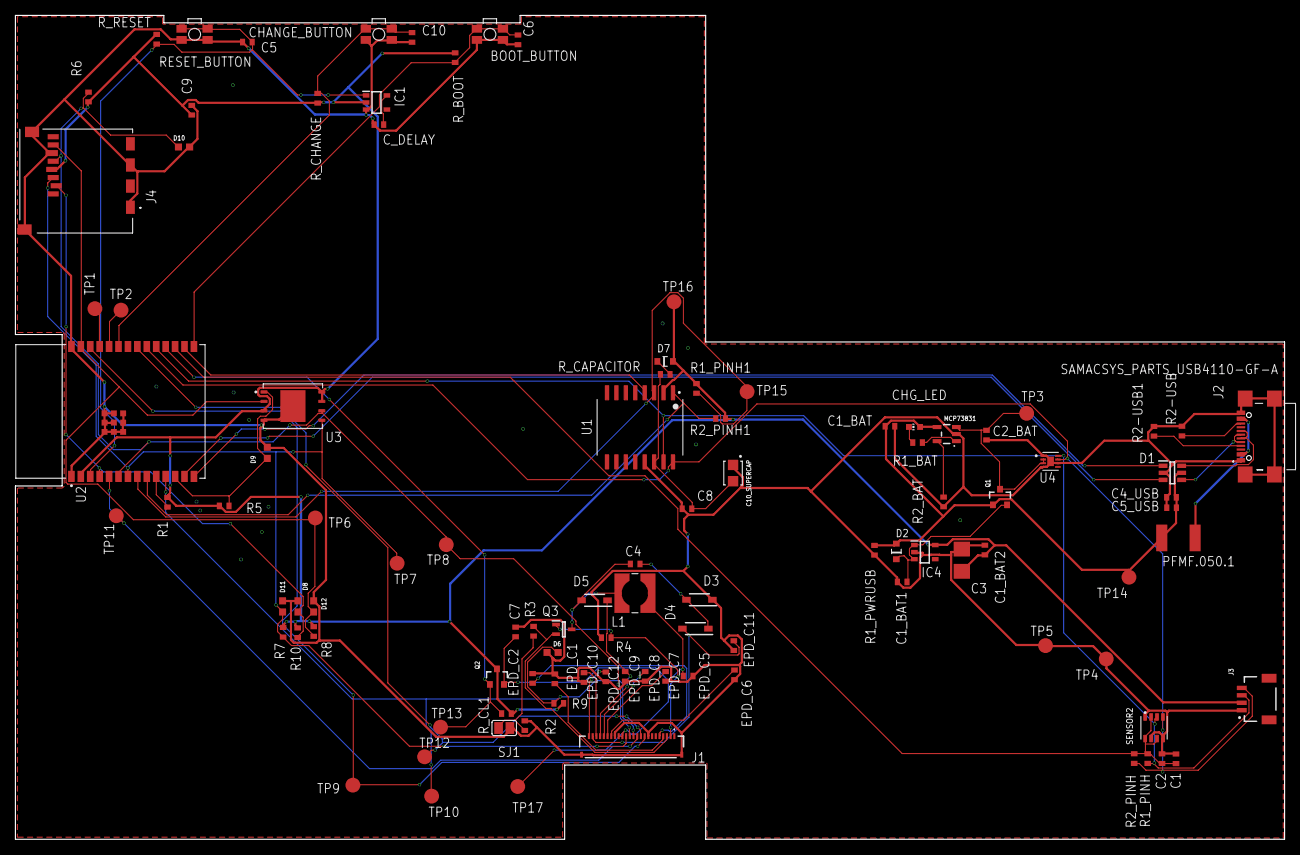
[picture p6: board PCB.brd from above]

Board: 2 copper layers, 171.0 x 111.0 mm, 103 parts (0 on the bottom side), 55 nets.

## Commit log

2025-03-29 Schematic done; working on PCB board
    [Electronics+Design.f3z, PCB.brd, Schematic.sch]
2025-04-06 Project finished
    [Bill_of_Materials.csv, PCB_v35.brd, Pick_and_Place.csv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]
2025-04-15 Added 3D models to PCB layout
    [PCB.brd, PCB_v35.brd, Schematic v27.sch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]

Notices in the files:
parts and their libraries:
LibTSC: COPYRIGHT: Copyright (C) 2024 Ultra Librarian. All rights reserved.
